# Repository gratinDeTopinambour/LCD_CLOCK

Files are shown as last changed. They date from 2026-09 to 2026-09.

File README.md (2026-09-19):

# ⏱️ LCD_CLOCK

A complete **open-source low-power LCD clock project** based on the **STM32U083RCT6** microcontroller.

This repository contains all the resources required to build the project:

- 📐 **3D Design**: Enclosure and mechanical parts for 3D printing.
- 🔌 **Electronics**: Schematics, PCB layout, BOM, Gerbers, and PDF documentation.
- 💻 **Firmware**: Embedded C software developed using STM32CubeIDE / STM32CubeMX.
- 🖥️ **LCD Display**: Direct driving of a 4-digit LCD display by the STM32.
- ⏰ **Timekeeping**: Utilizes the internal RTC and low-frequency LSE oscillator.
- 🔋 **Power Management**: Leverages low-power peripherals and STOP2 sleep mode.
- 🌡️ **Analog Measurements**: Temperature and battery voltage monitoring via ADC.
- 📖 **Documentation**: Technical files and documents needed for manufacturing and development.

---

## 🖼️ Project Overview

| LCD Clock |
| :---: |
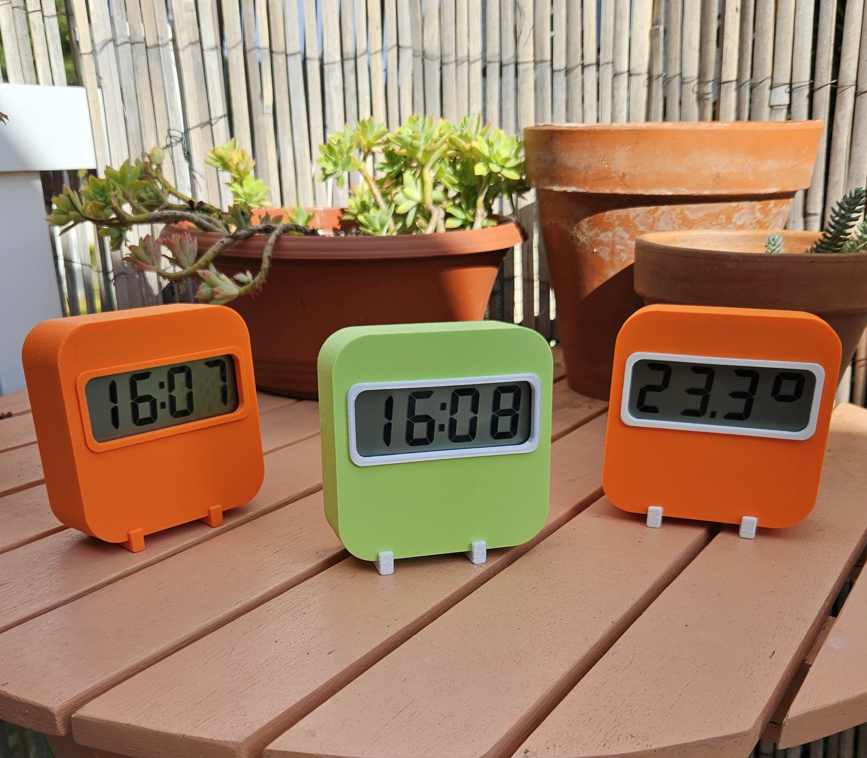
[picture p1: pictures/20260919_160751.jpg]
|  |
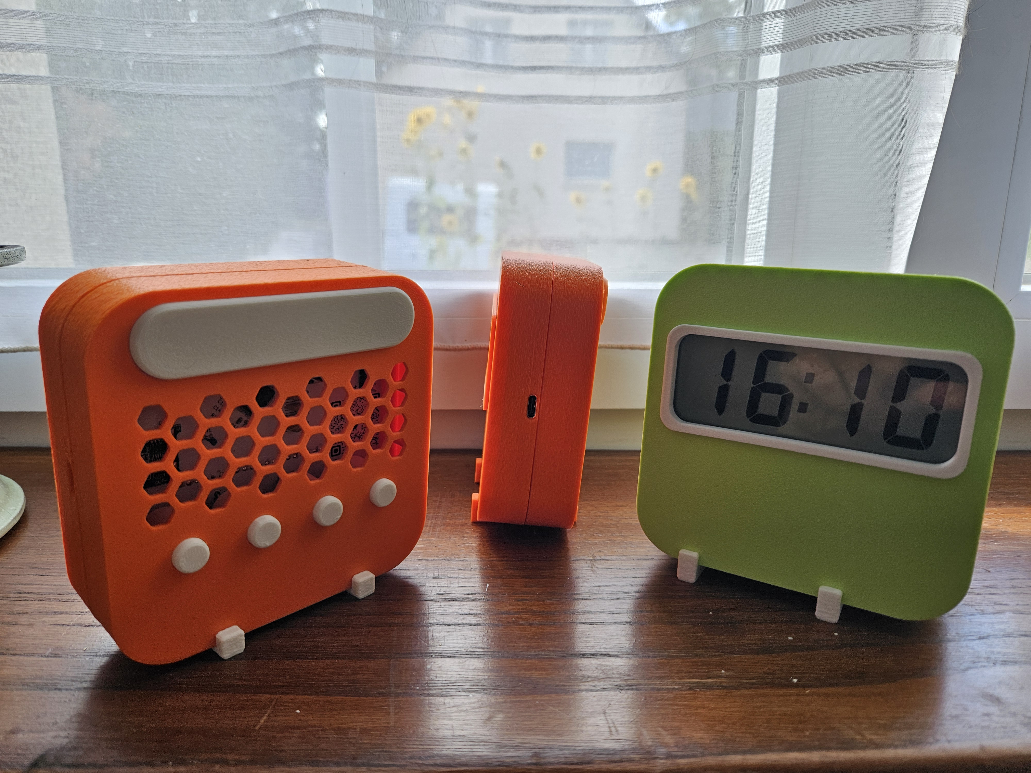
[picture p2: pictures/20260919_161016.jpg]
|  |

---

## 📂 Project Structure

```text
LCD_CLOCK/
│
├── 3D_design/                             # Mechanical design
│   ├── LCD_Clock_back.stl                 # Back part of the enclosure
│   ├── LCD_Clock_button_lumiere.stl       # Light control button
│   ├── LCD_Clock_button.stl               # Control button
│   ├── LCD_Clock_capot.stl                # Enclosure top cover
│   ├── LCD_Clock_dessous.stl              # Bottom part of the enclosure
│   ├── LCD_Clock_face_avant.stl           # Front panel
│   ├── LCD_Clock.3mf                      # Complete 3D project / model
│   └── LCD_Clock.step                     # STEP CAD model
│
├── Electronics/                           # Electronics design
│   ├── BOM/                               # Bill of Materials
│   ├── GERBER/                            # PCB manufacturing files
│   ├── KICAD/                             # KiCad project
│   └── PDF_version/                       # PDF electronics documentation
│
├── pictures/                              # Project photos
│   ├── 20260919_160751.jpg
│   └── 20260919_161016.jpg
│
├── Program/                               # STM32 firmware
│   ├── .settings/                         # STM32CubeIDE settings
│   ├── Core/                              # Application code and configuration
│   ├── Drivers/                           # Drivers and libraries
│   ├── .cproject                          # Eclipse project configuration
│   ├── .mxproject                         # STM32CubeMX configuration
│   ├── .project                           # STM32CubeIDE project file
│   ├── LCD_CLOCK Debug.launch             # Debug launch configuration
│   ├── LCD_CLOCK.ioc                      # STM32CubeMX configuration file
│   └── STM32U083RCTX_FLASH.ld             # Linker script
│
├── README.md                              # Main documentation
└── LICENSE                                # Project license

---

## ⚡ Technical Specifications

* **Microcontroller**: STM32U083RCT6 (Ultra-low-power ARM Cortex-M0+).
* **Display**: 4-digit LCD directly driven by the microcontroller.
* **Timekeeping**: RTC with LSE low-frequency oscillator.
* **Low Power**: Leverages RTC/LPTIM peripherals and STOP2 mode.
* **Measurements**: Temperature and battery voltage measured via ADC.
* **PCB Design**: Designed with **KiCad**, Gerber files and BOM included.
* **Power Supply**: Designed for battery operation.

---

## 🖨️ 3D Printed Enclosure

Parts are located in the `3D_design/` directory.

| Part | Format | Description |
| :--- | :--- | :--- |
| `LCD_Clock.3mf` | `.3mf` | 3D enclosure model |
| `LCD_Clock.step` | `.step` | CAD enclosure model |
| `LCD_Clock_capot.stl` | `.stl` | Top cover |
| `LCD_Clock_face_avant.stl` | `.stl` | Front panel |
| `LCD_Clock_back.stl` | `.stl` | Back part |
| `LCD_Clock_dessous.stl` | `.stl` | Bottom part |
| `LCD_Clock_button.stl` | `.stl` | Control button |
| `LCD_Clock_button_lumiere.stl` | `.stl` | Light control button |

---

## 💻 Firmware & Development

Source code is located in `Program/`.

### Prerequisites

* [STM32CubeIDE](https://www.st.com/en/development-tools/stm32cubeide.html) (recent version)
* Debugger / Programmer (ST-Link V2 / V3)

### Building and Flashing

1. Open **STM32CubeIDE**.
2. Import the project from `Program/`.
3. If you wish to modify peripheral configurations, open the `LCD_CLOCK.ioc` file.
4. Build (`Build Project`) then flash the microcontroller using the included debug configuration (`LCD_CLOCK Debug.launch`).

---

## 🏭 PCB Manufacturing

To manufacture the PCB:

1. Production-ready manufacturing files are located in `Electronics/GERBER/`.
2. The Bill of Materials (BOM) is available in `Electronics/BOM/`.
3. Original design files are available in `Electronics/KICAD/`.
4. Schematics and documentation are available in `Electronics/PDF_version/`.

---

## 📖 Documentation

Technical documentation for this project can be found in the `Electronics/PDF_version/` and `Program/` directories.

---

## 📜 License

This project is released under an open-source license. You are free to use, modify, and distribute it.

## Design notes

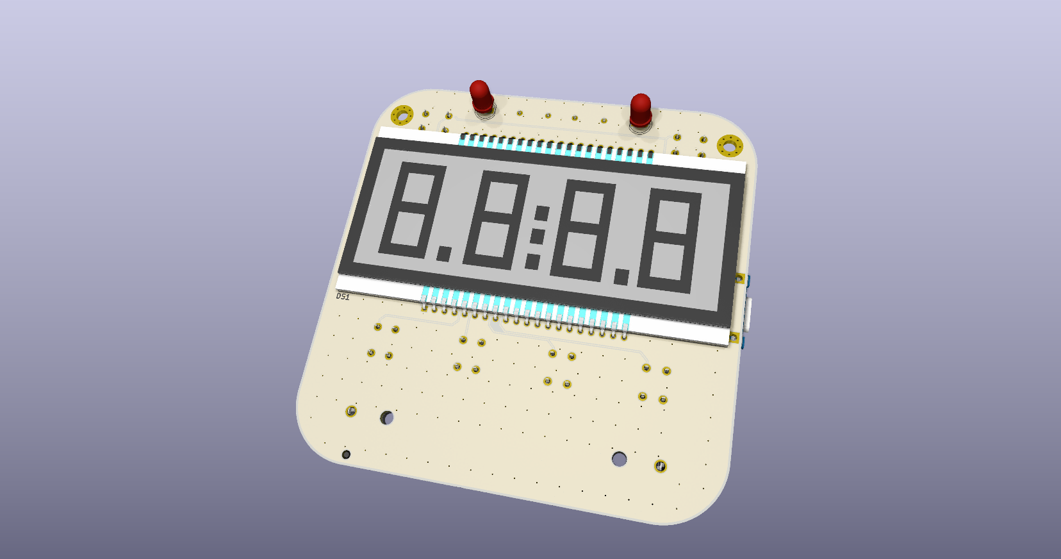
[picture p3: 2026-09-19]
Electronics/PDF_version/LCD_CLOCK_bottom.png

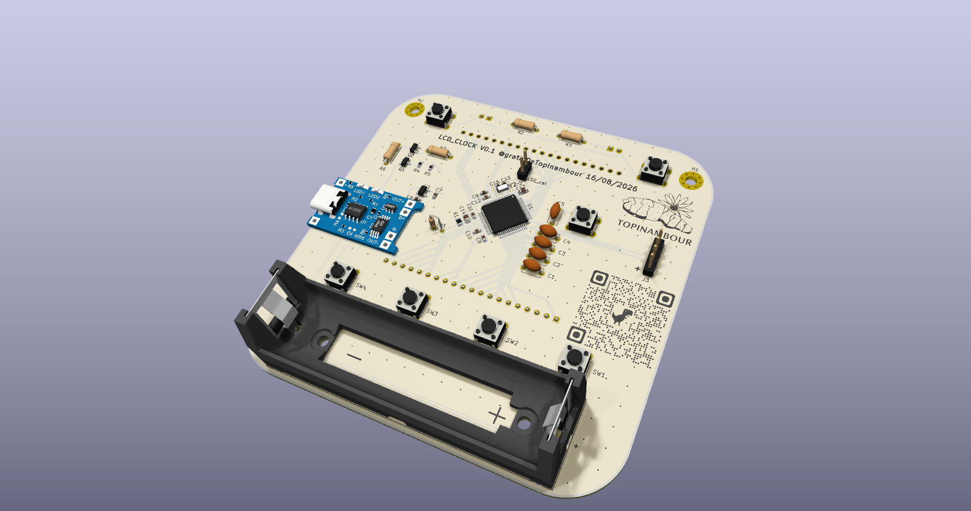
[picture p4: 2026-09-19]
Electronics/PDF_version/LCD_CLOCK.png

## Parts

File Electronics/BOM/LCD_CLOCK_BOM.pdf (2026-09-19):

Feuille1
Reference Value | Footprint
B1 | BHC-18650-1P
C1 | 100nF | C_Disc_D5.0mm_W2.5mm_P5.00mm
C2 | 100nF | C_Disc_D5.0mm_W2.5mm_P5.00mm
C3 | 100nF | C_Disc_D5.0mm_W2.5mm_P5.00mm
C4 | 100nF | C_Disc_D5.0mm_W2.5mm_P5.00mm
C5 | 100nF | C_Disc_D5.0mm_W2.5mm_P5.00mm
C6 | 1uF | 0603_1608Metric
C7 | 1uF | 0603_1608Metric
C8 | 100nF | 0603_1608Metric
C9 | 1uF | 0603_1608Metric
C10 | 1uF | 0603_1608Metric
C11 | 100nF | 0603_1608Metric
C12 | 100nF | 0603_1608Metric
C13 | 100nF | 0805_2012Metric
C14 | 100nF | 0805_2012Metric
C15 | 12pF | 0402_1005Metric
C16 | 12pF | 0402_1005Metric
D1 | LED | LED_D5.0mm
D2 | LED | LED_D5.0mm
DS1 | DE_158-RS-20_6.35 | DE158RS20635
Q1 | AO3401A | SOT-23
Q2 | AO3400A | SOT-23
R1 | 10k | 0805_2012Metric
R2 | 270
R3 | 270
R4 | 22k
R5 | 22k
R6 | 100k
R7 | 22k
SW1 | H1 | Button_Switch_THT:SW_PUSH_6mm_H5mm
SW2 | H2
SW3 | M1
SW4 | M2
SW5 | RST | Button_Switch_THT:SW_PUSH_6mm_H5mm
SW6 | Light | Button_Switch_THT:SW_PUSH_6mm_H5mm
SW7 | Light | Button_Switch_THT:SW_PUSH_6mm_H5mm
TH1 | TT7-10KC8-3
U1 | STM32U073R8Tx | LQFP-64_10x10mm_P0.5mm
U2 | TLV70233_SOT23-5 | SOT-23-5
Y2 | ABS07-32,768KHZ-1-T | ABS07

part | datasheet

DE158

TT7-10KC8-3++(rev+01)

stm32u073x8

# TME ref

BHC-18650-1P

CBR04C120F5GAC
CBR04C120F5GAC

DE158-RS-20/8.4
AO3401A
AO3400A

TT7-10KC3-11

STM32U073R8T6

ABS07-32.768KHZ-1

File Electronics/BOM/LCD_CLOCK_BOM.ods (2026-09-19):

Reference | Value | Footprint | part | datasheet | TME ref
B1 | BHC-18650-1P |  |  |  | BHC-18650-1P
C1 | 100nF | C_Disc_D5.0mm_W2.5mm_P5.00mm
C2 | 100nF | C_Disc_D5.0mm_W2.5mm_P5.00mm
C3 | 100nF | C_Disc_D5.0mm_W2.5mm_P5.00mm
C4 | 100nF | C_Disc_D5.0mm_W2.5mm_P5.00mm
C5 | 100nF | C_Disc_D5.0mm_W2.5mm_P5.00mm
C6 | 1uF | 0603_1608Metric
C7 | 1uF | 0603_1608Metric
C8 | 100nF | 0603_1608Metric
C9 | 1uF | 0603_1608Metric
C10 | 1uF | 0603_1608Metric
C11 | 100nF | 0603_1608Metric
C12 | 100nF | 0603_1608Metric
C13 | 100nF | 0805_2012Metric
C14 | 100nF | 0805_2012Metric
C15 | 12pF | 0402_1005Metric |  |  | CBR04C120F5GAC
C16 | 12pF | 0402_1005Metric |  |  | CBR04C120F5GAC
D1 | LED | LED_D5.0mm
D2 | LED | LED_D5.0mm
DS1 | DE_158-RS-20_6.35 | DE158RS20635 |  | DE158 | DE158-RS-20/8.4
Q1 | AO3401A | SOT-23 |  |  | AO3401A
Q2 | AO3400A | SOT-23 |  |  | AO3400A
R1 | 10k | 0805_2012Metric
R2 | 270
R3 | 270
R4 | 22k
R5 | 22k
R6 | 100k
R7 | 22k
SW1 | H1 | Button_Switch_THT:SW_PUSH_6mm_H5mm
SW2 | H2
SW3 | M1
SW4 | M2
SW5 | RST | Button_Switch_THT:SW_PUSH_6mm_H5mm
SW6 | Light | Button_Switch_THT:SW_PUSH_6mm_H5mm
SW7 | Light | Button_Switch_THT:SW_PUSH_6mm_H5mm
TH1 | TT7-10KC8-3 |  |  | TT7-10KC8-3++(rev+01) | TT7-10KC3-11
U1 | STM32U073R8Tx | LQFP-64_10x10mm_P0.5mm |  | stm32u073x8 | STM32U073R8T6
U2 | TLV70233_SOT23-5 | SOT-23-5
Y2 | ABS07-32,768KHZ-1-T | ABS07 |  |  | ABS07-32.768KHZ-1

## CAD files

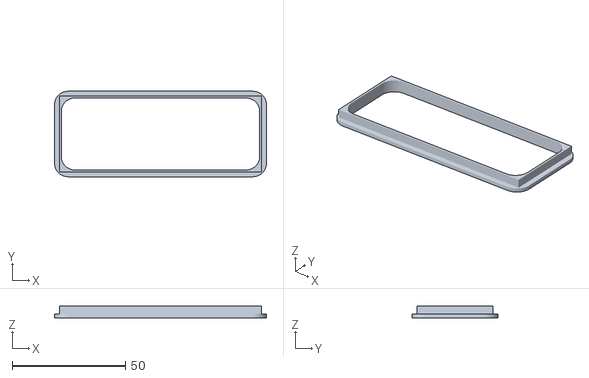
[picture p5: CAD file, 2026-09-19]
3D_design/LCD_Clock_face_avant.stl
93.5 x 37.8 x 5.10

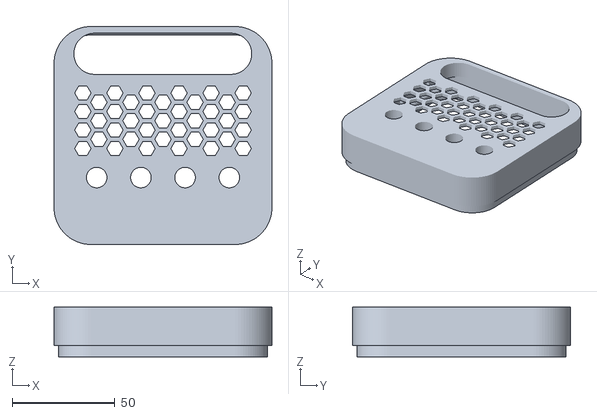
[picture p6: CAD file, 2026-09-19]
3D_design/LCD_Clock_back.stl
106.0 x 106.0 x 24.1

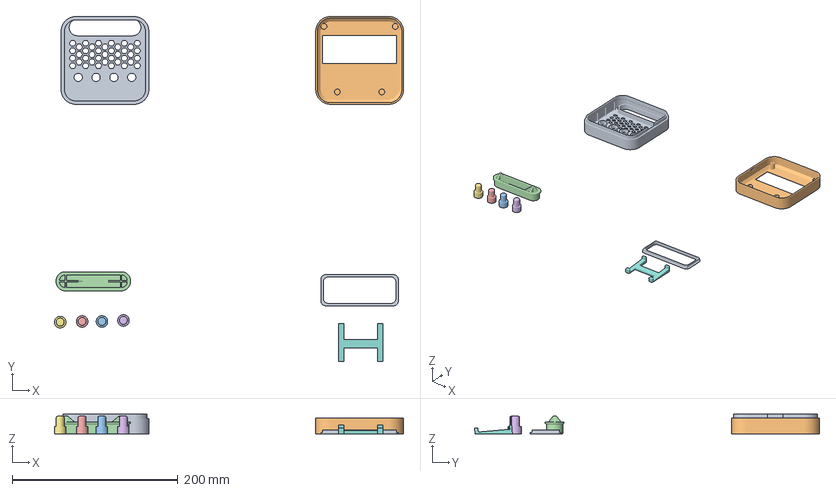
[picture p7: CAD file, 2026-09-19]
3D_design/LCD_Clock.3mf
421.2 x 416.2 x 24.1 mm
LCD_Clock_back.stl
LCD_Clock_capot.stl
LCD_Clock_boutton.stl x 4
LCD_Clock_boutton_lumiere.stl
LCD_Clock_dessous.stl
LCD_Clock_face_avant.stl

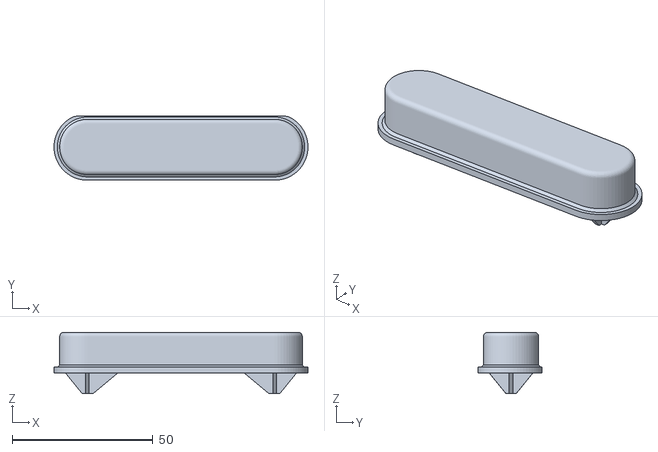
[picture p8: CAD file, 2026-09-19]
3D_design/LCD_Clock_boutton_lumiere.stl
90.1 x 22.9 x 21.8

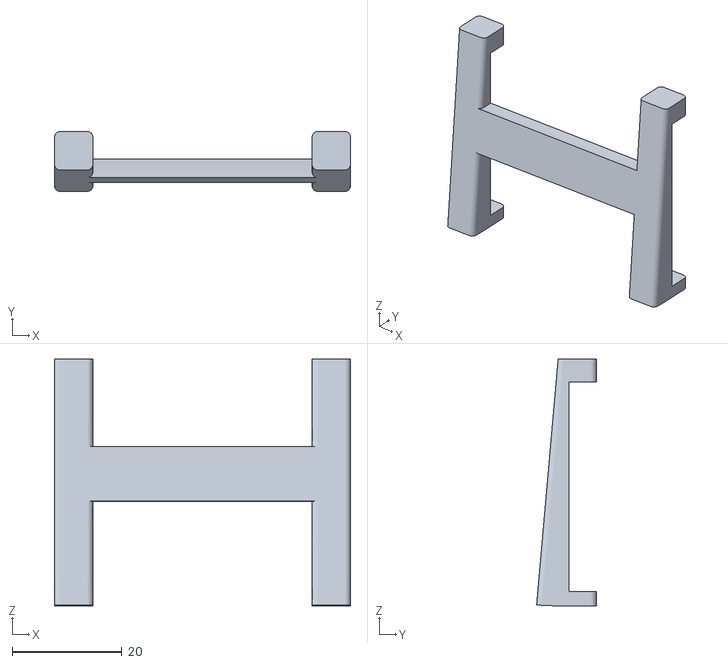
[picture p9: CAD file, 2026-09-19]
3D_design/LCD_Clock_dessous.stl
54.0 x 10.9 x 45.0

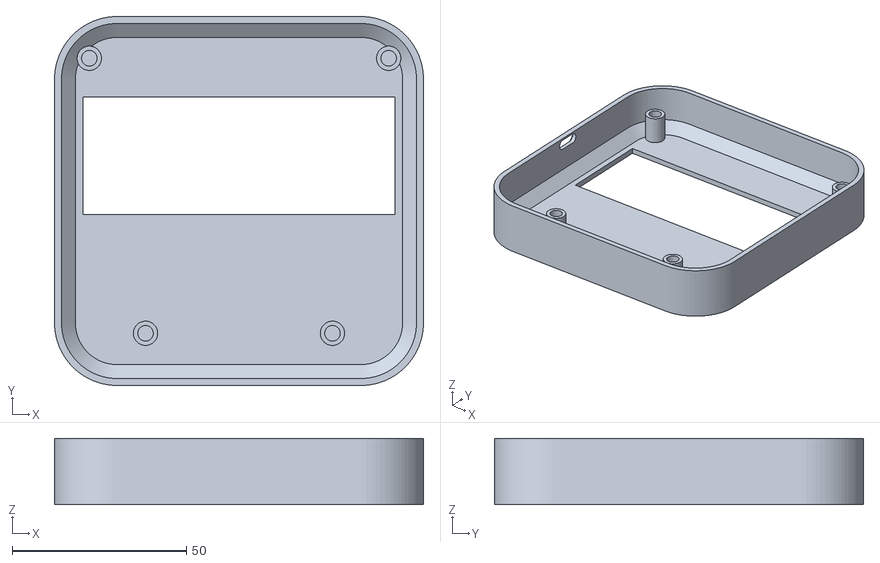
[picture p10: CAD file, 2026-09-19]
3D_design/LCD_Clock_capot.stl
106.0 x 106.0 x 19.0

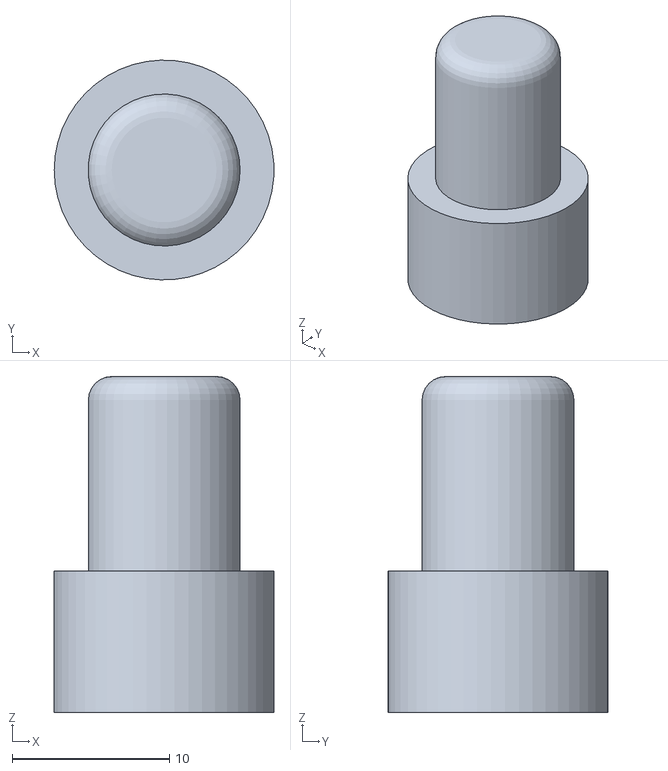
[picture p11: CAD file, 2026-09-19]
3D_design/LCD_Clock_boutton.stl
14.0 x 14.0 x 21.4

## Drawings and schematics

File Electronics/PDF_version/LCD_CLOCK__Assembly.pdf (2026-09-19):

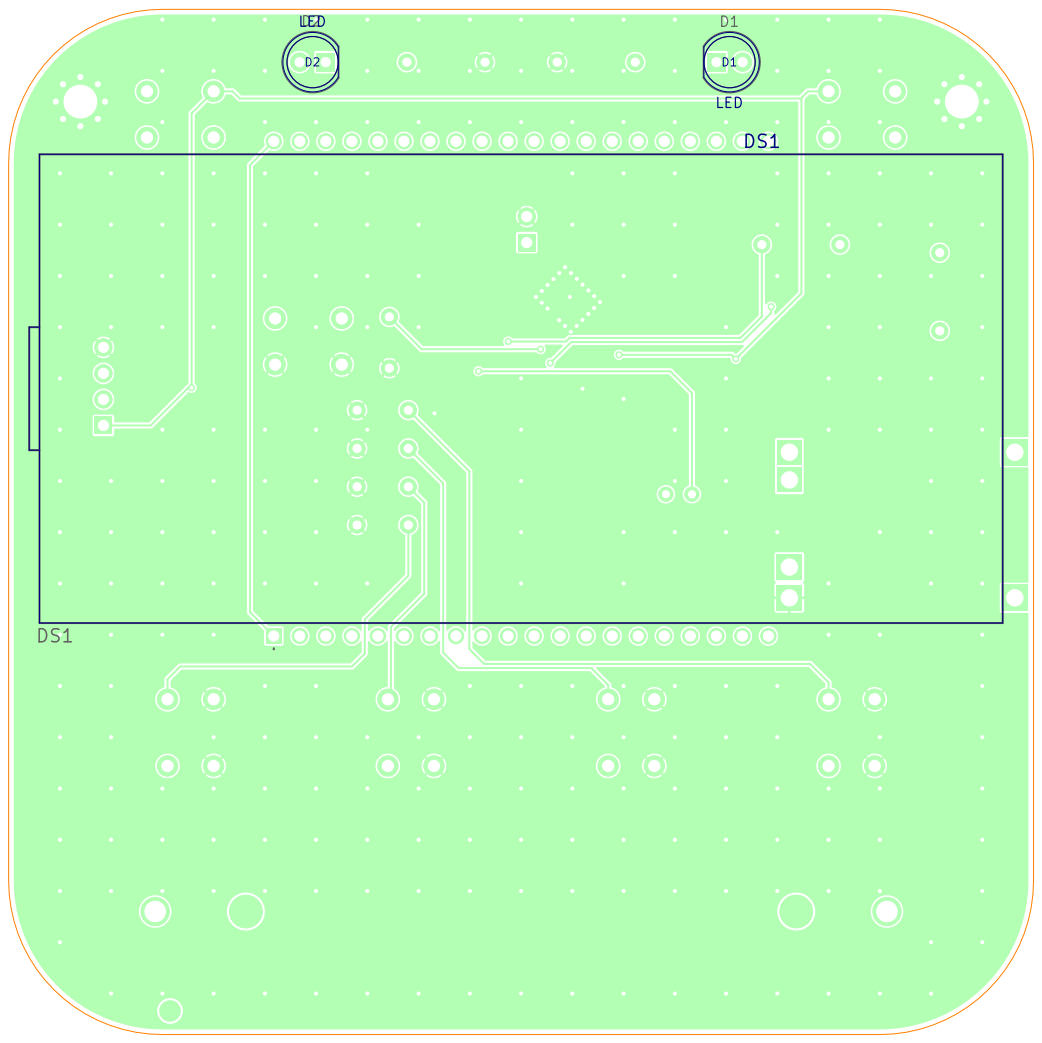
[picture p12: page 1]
D Date:; Size: A4; Rev:; LED; D1 LED

Board2Pdf: Colored BOT - Page 1/2

Sheet: Colored BOT
File: LCD_CLOCK.kicad_pcb
Title:
KiCad E.D.A. 10.0.3

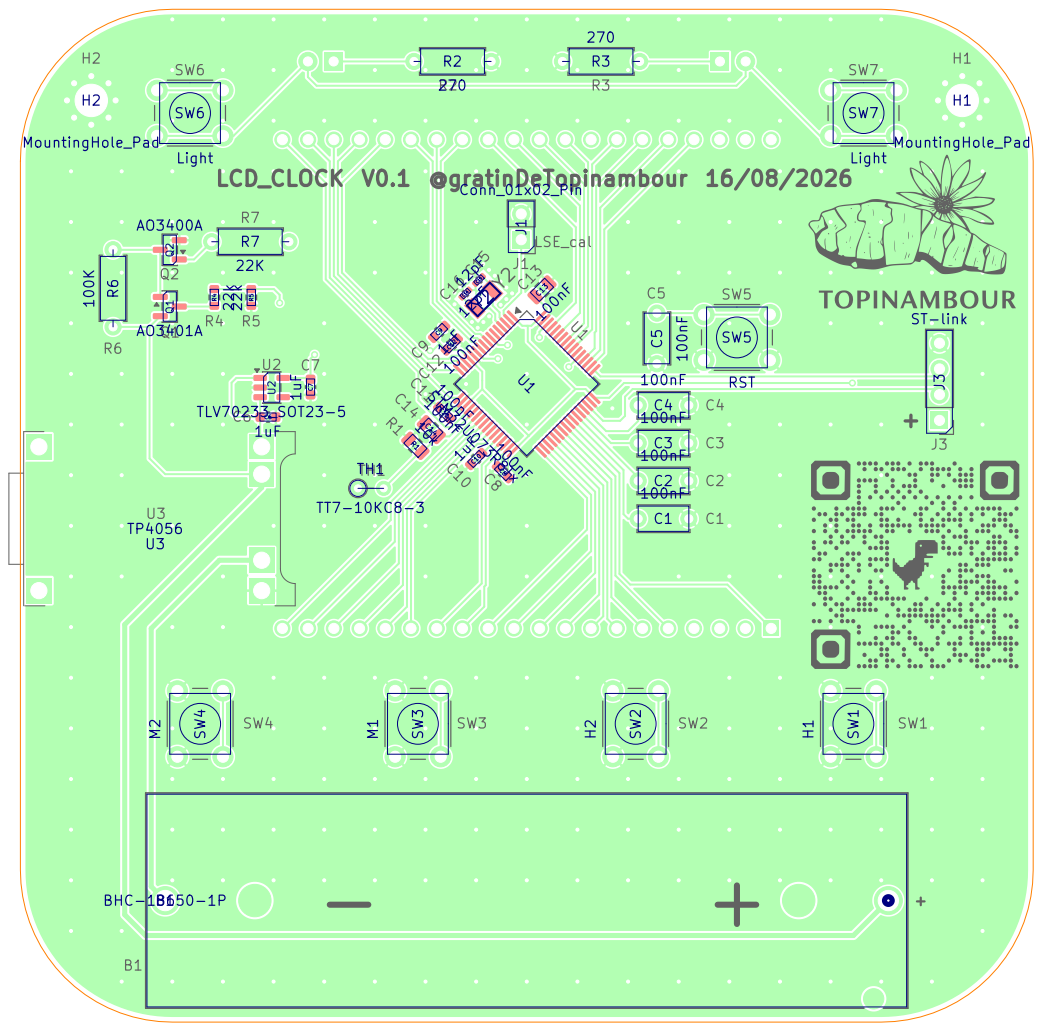
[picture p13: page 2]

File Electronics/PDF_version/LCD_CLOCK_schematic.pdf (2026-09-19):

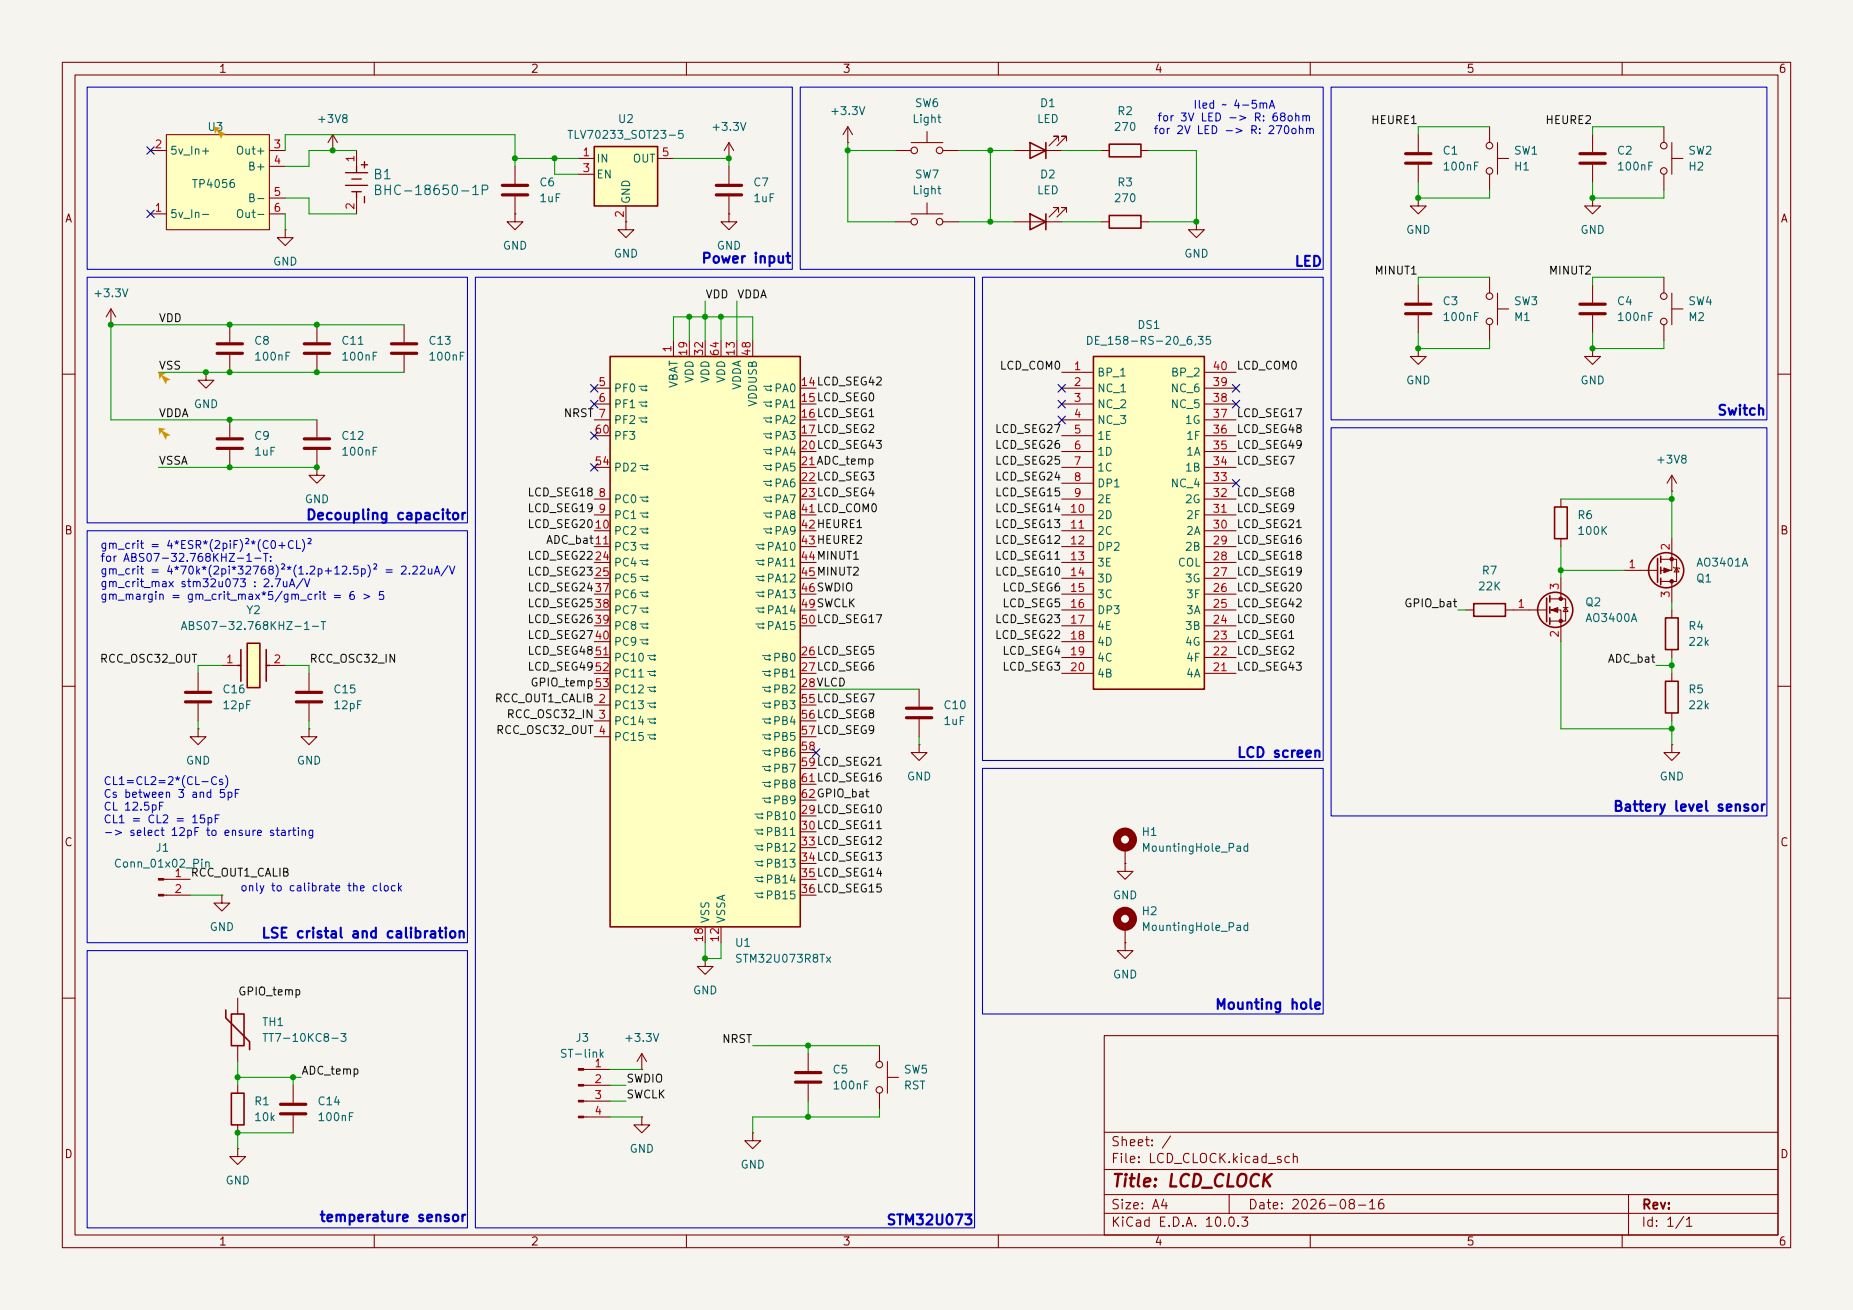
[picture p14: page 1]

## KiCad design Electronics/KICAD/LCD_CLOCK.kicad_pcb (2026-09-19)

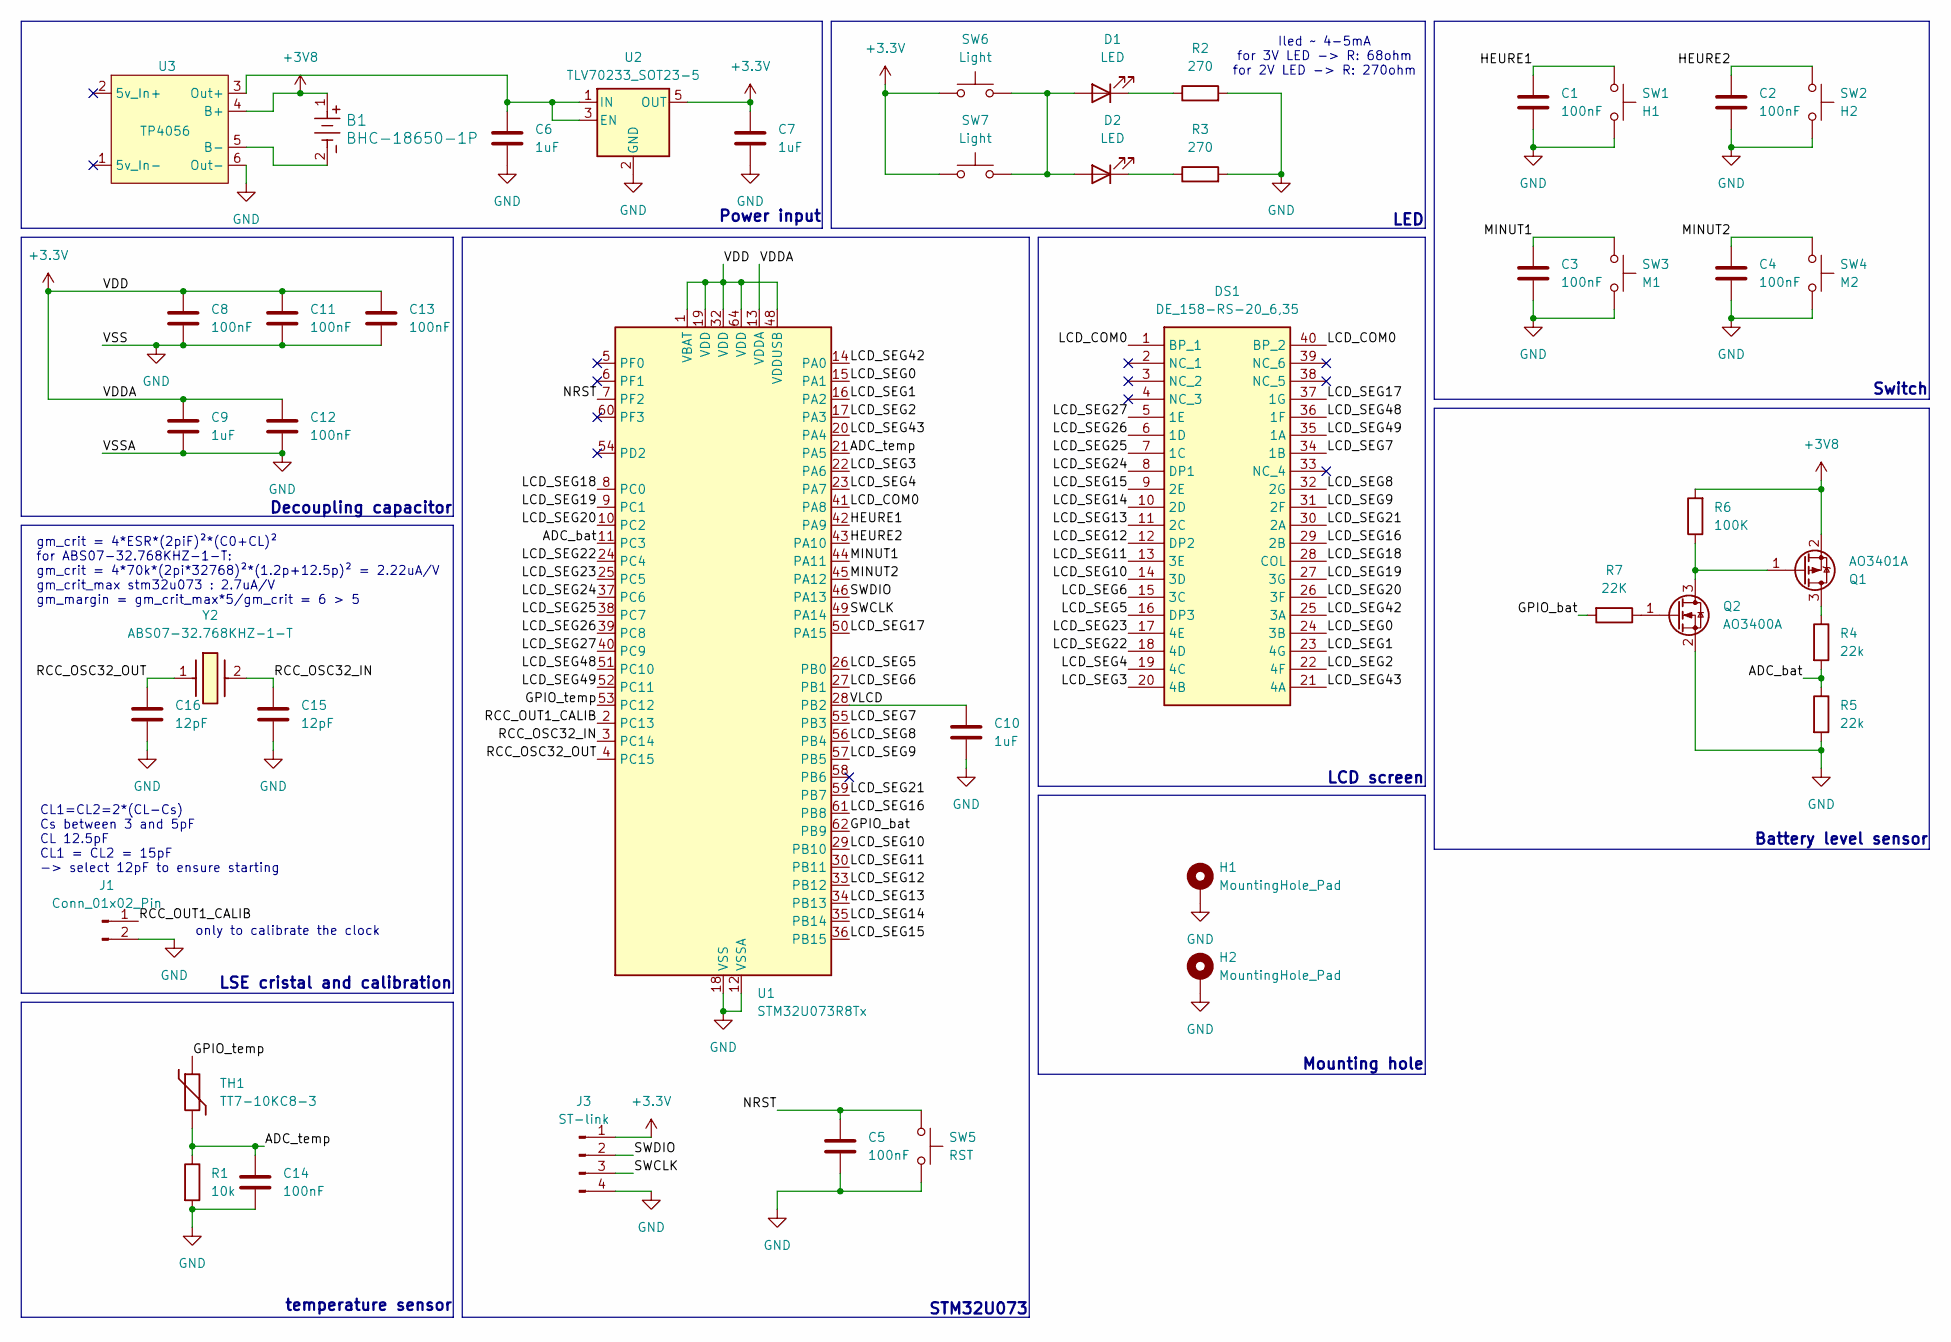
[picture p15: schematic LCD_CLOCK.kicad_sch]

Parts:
B1: BHC-18650-1P; BHC-18650-1P_COM
C1, C2, C3, C4, C5: 100nF; C_Disc_D5.0mm_W2.5mm_P5.00mm
C6, C7, C9, C10: 1uF; C_0603_1608Metric
C8, C11, C12: 100nF; C_0603_1608Metric
C13, C14: 100nF; C_0805_2012Metric
C15, C16: 12pF; C_0402_1005Metric
D1, D2: LED; LED_D5.0mm
DS1: DE_158-RS-20_6,35; DE158RS20635; Manufacturer_Part_Number DE 158-RS-20/6,35
H1, H2: MountingHole_Pad; MountingHole_3.2mm_M3_Pad_Via
J1: Conn_01x02_Pin; PinHeader_1x02_P2.54mm_Vertical
J3: ST-link; PinHeader_1x04_P2.54mm_Vertical
Q1: AO3401A; SOT-23
Q2: AO3400A; SOT-23
R1: 10k; R_0805_2012Metric
R2, R3: 270; R_Axial_DIN0207_L6.3mm_D2.5mm_P7.62mm_Horizontal
R4, R5: 22k; R_0603_1608Metric
R6: 100K; R_Axial_DIN0207_L6.3mm_D2.5mm_P7.62mm_Horizontal
R7: 22K; R_Axial_DIN0207_L6.3mm_D2.5mm_P7.62mm_Horizontal
SW1: H1; SW_PUSH_6mm_H5mm
SW2: H2; SW_PUSH_6mm_H5mm
SW3: M1; SW_PUSH_6mm_H5mm
SW4: M2; SW_PUSH_6mm_H5mm
SW5: RST; SW_PUSH_6mm_H5mm
SW6, SW7: Light; SW_PUSH_6mm_H5mm
TH1: TT7-10KC8-3; R_Axial_DIN0204_L3.6mm_D1.6mm_P2.54mm_Vertical
U1: STM32U073R8Tx; LQFP-64_10x10mm_P0.5mm
U2: TLV70233_SOT23-5; SOT-23-5
U3: TP4056; Module_TP4056
Y2: ABS07-32.768KHZ-1-T; ABS07; Manufacturer_Part_Number ABS07-32.768KHZ-1-T

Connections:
+3.3V: C7.1, C8.1, C9.1, C11.1, C12.1, C13.1, J3.1, SW6.1, SW7.1, U1.1 (VBAT), U1.13 (VDDA), U1.19 (VDD), U1.32 (VDD), U1.48 (VDDUSB), U1.64 (VDD), U2.5 (OUT)
+3V8: B1.1, Q1.2 (S), R6.2, U3.4 (B+)
/ADC_bat: R4.2, R5.1, U1.11 (PC3)
/ADC_temp: C14.1, R1.1, TH1.2, U1.21 (PA5)
/GPIO_bat: R7.2, U1.62 (PB9)
/GPIO_temp: TH1.1, U1.53 (PC12)
/HEURE1: C1.2, SW1.1, U1.42 (PA9)
/HEURE2: C2.2, SW2.1, U1.43 (PA10)
/LCD_COM0: DS1.1 (BP_1), DS1.40 (BP_2), U1.41 (PA8)
/LCD_SEG0: DS1.24 (3B), U1.15 (PA1)
/LCD_SEG1: DS1.23 (4G), U1.16 (PA2)
/LCD_SEG2: DS1.22 (4F), U1.17 (PA3)
/LCD_SEG3: DS1.20 (4B), U1.22 (PA6)
/LCD_SEG4: DS1.19 (4C), U1.23 (PA7)
/LCD_SEG5: DS1.16 (DP3), U1.26 (PB0)
/LCD_SEG6: DS1.15 (3C), U1.27 (PB1)
/LCD_SEG7: DS1.34 (1B), U1.55 (PB3)
/LCD_SEG8: DS1.32 (2G), U1.56 (PB4)
/LCD_SEG9: DS1.31 (2F), U1.57 (PB5)
/LCD_SEG10: DS1.14 (3D), U1.29 (PB10)
/LCD_SEG11: DS1.13 (3E), U1.30 (PB11)
/LCD_SEG12: DS1.12 (DP2), U1.33 (PB12)
/LCD_SEG13: DS1.11 (2C), U1.34 (PB13)
/LCD_SEG14: DS1.10 (2D), U1.35 (PB14)
/LCD_SEG15: DS1.9 (2E), U1.36 (PB15)
/LCD_SEG16: DS1.29 (2B), U1.61 (PB8)
/LCD_SEG17: DS1.37 (1G), U1.50 (PA15)
/LCD_SEG18: DS1.28 (COL), U1.8 (PC0)
/LCD_SEG19: DS1.27 (3G), U1.9 (PC1)
/LCD_SEG20: DS1.26 (3F), U1.10 (PC2)
/LCD_SEG21: DS1.30 (2A), U1.59 (PB7)
/LCD_SEG22: DS1.18 (4D), U1.24 (PC4)
/LCD_SEG23: DS1.17 (4E), U1.25 (PC5)
/LCD_SEG24: DS1.8 (DP1), U1.37 (PC6)
/LCD_SEG25: DS1.7 (1C), U1.38 (PC7)
/LCD_SEG26: DS1.6 (1D), U1.39 (PC8)
/LCD_SEG27: DS1.5 (1E), U1.40 (PC9)
/LCD_SEG42: DS1.25 (3A), U1.14 (PA0)
/LCD_SEG43: DS1.21 (4A), U1.20 (PA4)
/LCD_SEG48: DS1.36 (1F), U1.51 (PC10)
/LCD_SEG49: DS1.35 (1A), U1.52 (PC11)
/MINUT1: C3.2, SW3.1, U1.44 (PA11)
/MINUT2: C4.2, SW4.1, U1.45 (PA12)
/NRST: C5.2, SW5.1, U1.7 (PF2)
/RCC_OSC32_IN: C15.1, U1.3 (PC14), Y2.2
/RCC_OSC32_OUT: C16.1, U1.4 (PC15), Y2.1
/RCC_OUT1_CALIB: J1.1, U1.2 (PC13)
/SWCLK: J3.3, U1.49 (PA14)
/SWDIO: J3.2, U1.46 (PA13)
/VLCD: C10.1, U1.28 (PB2)
GND: C1.1, C2.1, C3.1, C4.1, C5.1, C6.2, C7.2, C8.2, C9.2, C10.2, C11.2, C12.2, C13.2, C14.2, C15.2, C16.2, H1.1 (1_1), H2.1 (1_1), J1.2, J3.4, Q2.2 (S), R1.2, R2.2, R3.2, R5.2, SW1.2, SW2.2, SW3.2, SW4.2, SW5.2, U1.12 (VSSA), U1.18 (VSS), U1.31 (VSS), U1.47 (VSS), U1.63 (VSS), U2.2 (GND), U3.6 (Out-)
unnamed: D1.2 (A), D2.2 (A), SW6.2, SW7.2
unnamed: D1.1 (K), R2.1
unnamed: D2.1 (K), R3.1
unnamed: Q1.3 (D), R4.1
unnamed: Q1.1 (G), Q2.3 (D), R6.1
unnamed: Q2.1 (G), R7.1
unnamed: C6.1, U2.1 (IN), U2.3 (EN), U3.3 (Out+)
unnamed: B1.2, U3.5 (B-)

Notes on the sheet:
LCD screen
Power input
Battery level sensor
LED
Switch
Iled ~ 4-5mA for 3V LED -> R: 68ohm for 2V LED -> R: 270ohm
CL1=CL2=2*(CL-Cs) Cs between 3 and 5pF CL 12.5pF CL1 = CL2 = 15pF -> select 12pF to ensure starting
STM32U073
Decoupling capacitor
LSE cristal and calibration
Mounting hole
temperature sensor
gm_crit = 4*ESR*(2piF)²*(C0+CL)² for ABS07-32.768KHZ-1-T: gm_crit = 4*70k*(2pi*32768)²*(1.2p+12.5p)² = 2.22uA/V gm_crit_max stm32u073 : 2.7uA/V gm_margin = gm_crit_max*5/gm_crit = 6 > 5
only to calibrate the clock

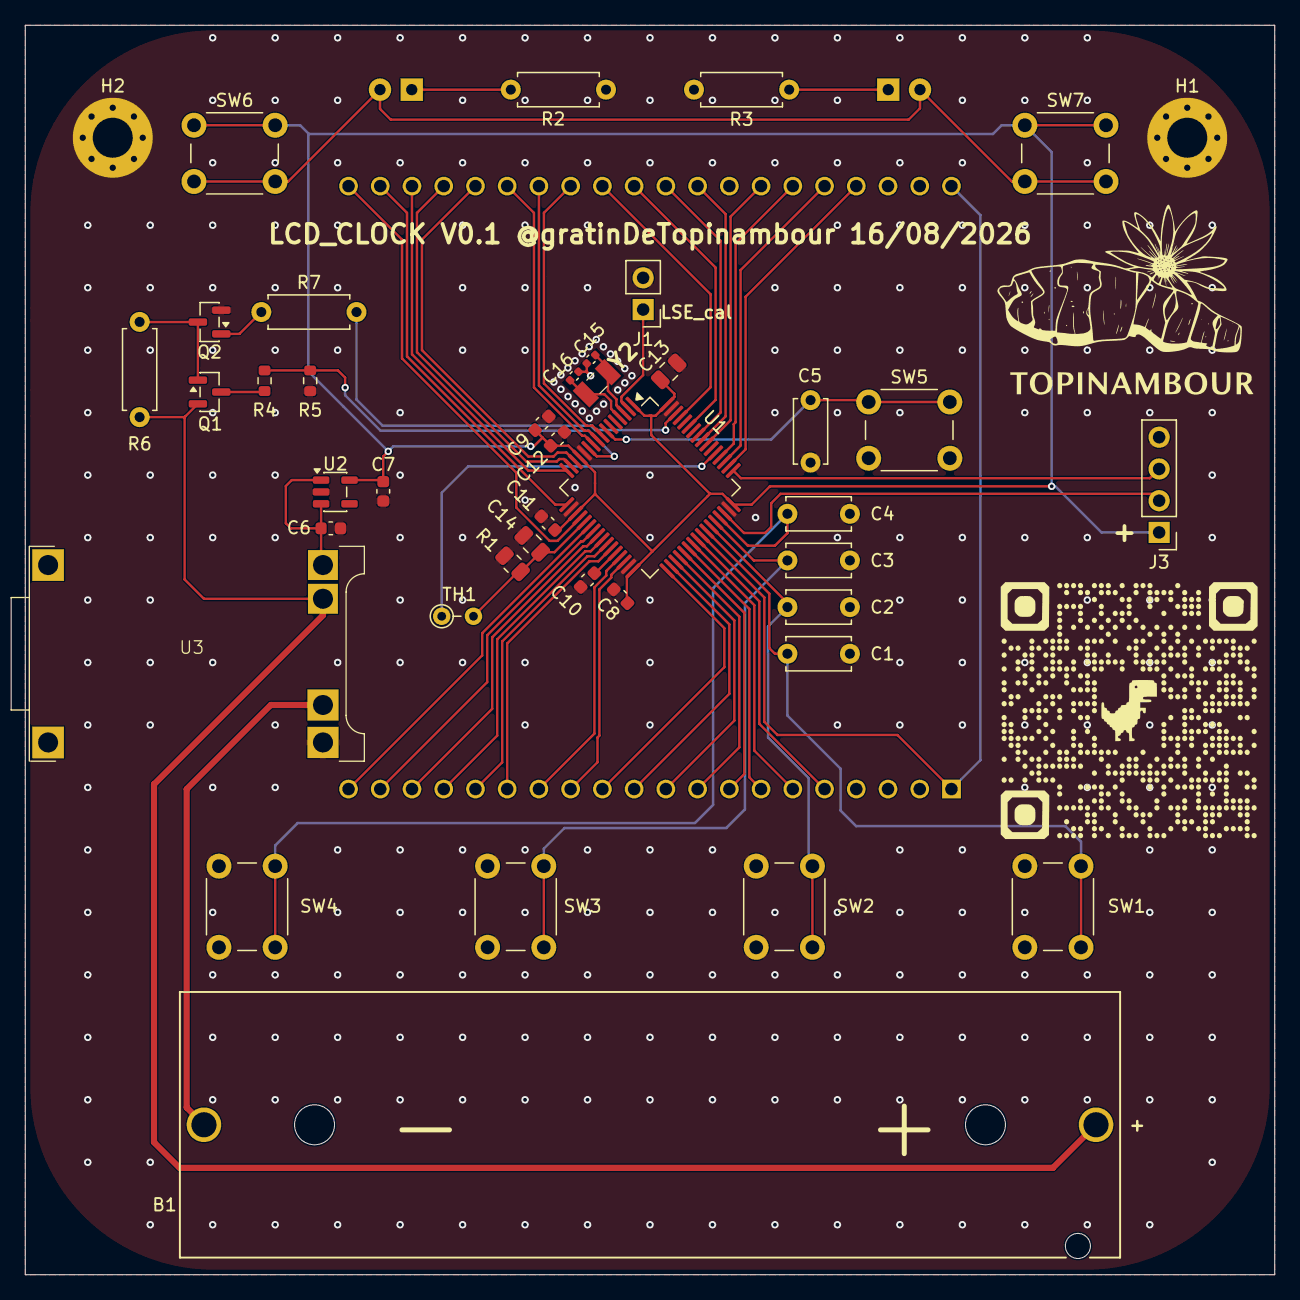
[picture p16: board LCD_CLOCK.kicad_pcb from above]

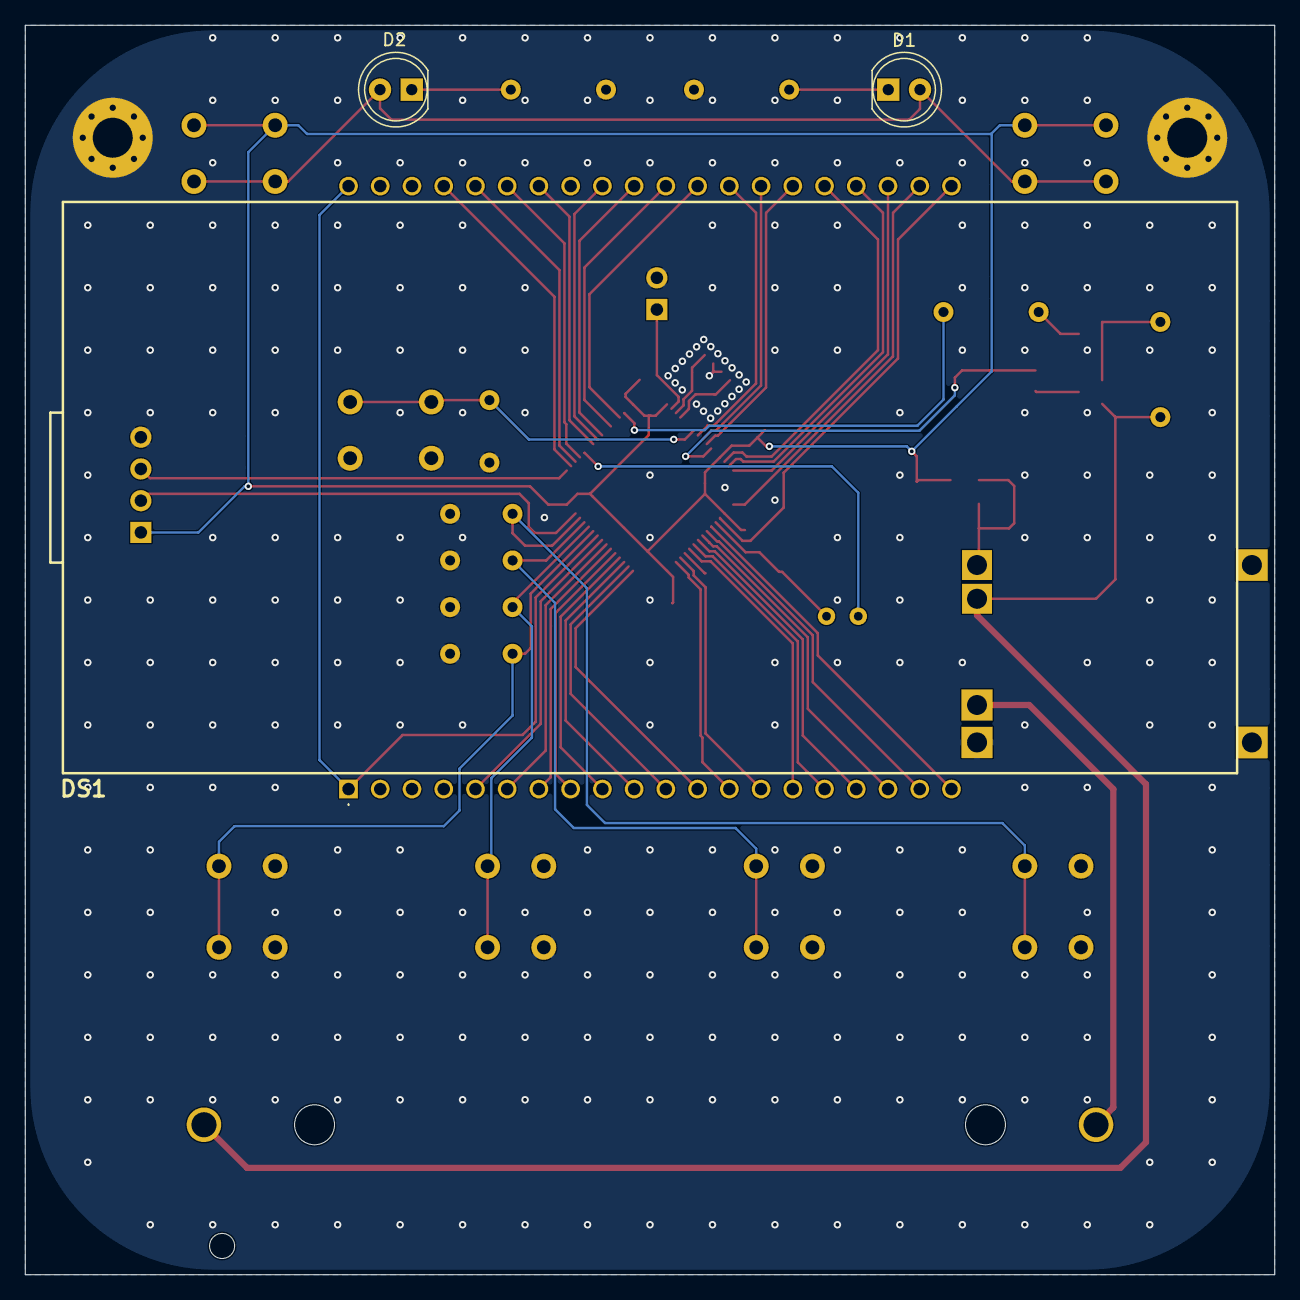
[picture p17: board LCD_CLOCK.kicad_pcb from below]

Board: 2 copper layers, 100.0 x 100.0 mm, 45 parts (3 on the bottom side), 59 nets.

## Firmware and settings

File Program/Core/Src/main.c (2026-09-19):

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
/* Includes ------------------------------------------------------------------*/
#include "main.h"

/* USER CODE BEGIN Includes */
#include "math.h"
#include "LCD_4DIGIT.h"
#include <stdio.h>
/* USER CODE END Includes */

/* USER CODE BEGIN PD */

//variable for TT7-10KC3-11 thermistor
#define R0_NTC 10000.0f
#define T0_NTC 298.15f
#define BETA_NTC 3977.0f
#define R_SERIE 9990.0f
/* USER CODE END PD */

ADC_HandleTypeDef hadc1;
DMA_HandleTypeDef hdma_adc1;

LCD_HandleTypeDef hlcd;

LPTIM_HandleTypeDef hlptim1;
LPTIM_HandleTypeDef hlptim2;

RTC_HandleTypeDef hrtc;

/* USER CODE BEGIN PV */
volatile Flag system_flag = {0};
State system_state = START;
uint16_t temp_value;
uint16_t bat_value;
uint8_t sleep_time = 0;
volatile uint8_t StopMode_Activated = 0;
uint32_t start;

volatile uint16_t adc_dma_buffer[2];

RTC_TimeTypeDef Time = {0};
RTC_DateTypeDef Date = {0};
/* USER CODE END PV */

void SystemClock_Config(void);
static void MX_GPIO_Init(void);
static void MX_DMA_Init(void);
static void MX_ADC1_Init(void);
static void MX_LCD_Init(void);
static void MX_RTC_Init(void);
static void MX_LPTIM1_Init(void);
static void MX_LPTIM2_Init(void);
/* USER CODE BEGIN 0 */
void mini_sprintf(int n, char *s, uint8_t width, char pad)
{

	s[width-1] = '\0';

    for (int8_t i = width - 2; i >= 0; i--) {
        // 2. Fill digits using the absolute value
        if (n > 0 || (i == width - 2 && n == 0)) {
            s[i] = (n % 10) + '0';
            n /= 10;
        }
        // 4. Fill remaining space with padding
        else {
            s[i] = pad;
        }
    }
}

State switch_state(Flag sys_flag)
{
	State state = START;

	if(sys_flag.need_calibration > 400) state = CALIBRATION;
	else if(sys_flag.adc_update)  state = ADC_MEASUREMENT;
	else if(sys_flag.adc_ready)  state = ADC_READ;
	else if(sys_flag.wait_adc) state = WAIT_FOR_ADC;
	else if(sys_flag.bat_update)  state = PRINT_BAT;
	else if(sys_flag.time_update) state = PRINT_TIME;
	else if(sys_flag.temp_update) state = PRINT_TEMP;
	else state = SLEEP_MODE;

	return state;
}

uint8_t Read_ADC(uint16_t *temp_val, uint16_t *bat_val)
{
	float temp_celsius = 0;
	int ADC_temp_value = 0;
	float R_ADC = 0;

	int ADC_bat_value = 0;

	HAL_GPIO_WritePin(BAT_ADC_ENABLE_GPIO_Port, BAT_ADC_ENABLE_Pin, RESET);
	HAL_GPIO_WritePin(TEMP_ADC_ENABLE_GPIO_Port, TEMP_ADC_ENABLE_Pin, RESET);

	ADC_temp_value = adc_dma_buffer[0];
	ADC_bat_value = adc_dma_buffer[1];

	if(ADC_temp_value < 1058) //temp < 0°C
	{
		*temp_val = 0;
	}
	else
	{
		R_ADC = R_SERIE*((4095.0f/(float)ADC_temp_value) - 1.0f);

		float steinhart = logf(R_ADC / R0_NTC) / BETA_NTC;
		steinhart += 1.0f / T0_NTC;
		temp_celsius = (1.0f / steinhart) - 273.15f;
		*temp_val = (uint16_t)(temp_celsius * 10.0f);
	}

	*bat_val = (uint16_t)(660.0*(float)ADC_bat_value/4096.0);


	return 0;
}

uint8_t Print_temp(uint16_t temp_val)
{
	char temp_txt[5] = "   *";

	mini_sprintf(temp_val, temp_txt, sizeof(temp_txt), ' ');

	for (uint8_t i = 0; i < 3; i++) {
		temp_txt[i] = temp_txt[i + 1];
	}

	temp_txt[3] = '*';
	LCD_WriteDigit(temp_txt,0b0010);

	return 0;
}

uint8_t Print_time(uint8_t hour, uint8_t minute)
{
	char time_txt[5] = "0000";
	char minute_txt[3] = "00";

	mini_sprintf(minute, minute_txt, sizeof(minute_txt), '0');
	mini_sprintf(hour, time_txt, sizeof(time_txt), '0');

	for (uint8_t i = 0; i < 2; i++) {
		time_txt[i] = time_txt[i + 2];
	}

	time_txt[2] = minute_txt[0];
	time_txt[3] = minute_txt[1];

	LCD_WriteDigit(time_txt,0b1000);

	return 0;
}

/* USER CODE END 0 */

/**
  * @brief  The application entry point.
  * @retval int
  */
int main(void)
{

  /* MCU Configuration--------------------------------------------------------*/

  /* Reset of all peripherals, Initializes the Flash interface and the Systick. */
  HAL_Init();

  /* Configure the system clock */
  SystemClock_Config();

  /* Initialize all configured peripherals */
  MX_GPIO_Init();
  MX_DMA_Init();
  MX_ADC1_Init();
  MX_LCD_Init();
  MX_RTC_Init();
  MX_LPTIM1_Init();
  MX_LPTIM2_Init();
  /* USER CODE BEGIN 2 */

  HAL_LCD_Clear(&hlcd);

  Time.Hours = 0;
  Time.Minutes = 0;
  Time.Seconds = 0;
  HAL_RTC_SetTime(&hrtc, &Time, RTC_FORMAT_BIN);

  system_flag.adc_update = 1;
  system_flag.need_calibration = 401;
  system_flag.time_update = 1;
//  HAL_RCCEx_PeriphCLKConfig();

  HAL_LPTIM_Counter_Start_IT(&hlptim1);
  HAL_LPTIM_Counter_Start_IT(&hlptim2);

  /* USER CODE END 2 */

  /* Infinite loop */
  /* USER CODE BEGIN WHILE */
  while (1)
  {
	  switch (system_state)
	  {
	  case START:

		  system_state = switch_state(system_flag);
		  break;

	  case CALIBRATION:

		  HAL_ADCEx_Calibration_Start(&hadc1);
		  system_flag.need_calibration = 0;

		  system_state = switch_state(system_flag);
		  break;

	  case ADC_READ:

		  Read_ADC(&temp_value, &bat_value);

		  system_flag.adc_ready = 0;
		  system_flag.wait_adc = 0;

		  if(bat_value < 340)
		  {
			  system_flag.low_battery = 1;
		  }

		  system_state = switch_state(system_flag);
		  break;

	  case ADC_MEASUREMENT:

		  HAL_GPIO_WritePin(TEMP_ADC_ENABLE_GPIO_Port, TEMP_ADC_ENABLE_Pin, SET);
		  HAL_GPIO_WritePin(BAT_ADC_ENABLE_GPIO_Port, BAT_ADC_ENABLE_Pin, SET);

		  start = HAL_GetTick();

		  while ((HAL_GetTick() - start) < 10);

		  HAL_ADC_Start_DMA(&hadc1, (uint32_t*)adc_dma_buffer, 2);

		  system_flag.adc_update = 0;
		  system_flag.wait_adc = 1;

		  system_state = switch_state(system_flag);
		  break;

	  case WAIT_FOR_ADC:

		  system_flag.wait_adc = 1;

		  system_state = switch_state(system_flag);
		  break;

	  case PRINT_TIME:

		  system_flag.time_update = 0;

		  Print_time(Time.Hours, Time.Minutes);

		  sleep_time = 5;

		  system_state = switch_state(system_flag);
		  break;

	  case PRINT_TEMP:

		  system_flag.temp_update = 0;

		  Print_temp(temp_value);

		  sleep_time = 3;

		  system_state = switch_state(system_flag);
		  break;

	  case PRINT_BAT:

		  system_flag.bat_update = 0;

		  LCD_WriteDigit("batt", 0);

		  if(bat_value > 344)
		  {
			  system_flag.low_battery = 0;
		  }

		  sleep_time = 20;

		  system_state = switch_state(system_flag);
		  break;

	  case SLEEP_MODE:

		  if(sleep_time > 1)
		  {
			  HAL_RTCEx_SetWakeUpTimer_IT(&hrtc, sleep_time-1, RTC_WAKEUPCLOCK_CK_SPRE_16BITS, 0);
			  StopMode_Activated = 1;
			  HAL_SuspendTick();
			  HAL_PWREx_EnterSTOP2Mode(PWR_SLEEPENTRY_WFI);

			  HAL_RTCEx_DeactivateWakeUpTimer(&hrtc);
		  }

		  HAL_RTC_GetTime(&hrtc, &Time, RTC_FORMAT_BIN);
		  HAL_RTC_GetDate(&hrtc, &Date, RTC_FORMAT_BIN);

		  if(system_flag.low_battery) system_flag.bat_update = 1;
		  else if(sleep_time == 5) system_flag.temp_update = 1;
		  else if(sleep_time == 3) system_flag.time_update = 1;

		  system_state = switch_state(system_flag);
		  break;

	  default:
		  system_state = START;
		  break;
	  }
    /* USER CODE END WHILE */

    /* USER CODE BEGIN 3 */
  }
  /* USER CODE END 3 */
}

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
/* USER CODE BEGIN 4 */
/**
  * @brief  EXTI line detection callback.
  * @param  GPIO_Pin Specifies the port pin connected to corresponding EXTI line.
  * @retval None
  */
void HAL_GPIO_EXTI_Falling_Callback(uint16_t GPIO_Pin)
{

  if(StopMode_Activated == 1)
  {
	  SystemClock_Config();
	  HAL_ResumeTick();
	  StopMode_Activated = 0;
  }

  HAL_RTC_GetTime(&hrtc, &Time, RTC_FORMAT_BIN);
  HAL_RTC_GetDate(&hrtc, &Date, RTC_FORMAT_BIN);

  if(GPIO_Pin == MINUT2_Pin)
  {
	  Time.Minutes = (Time.Minutes + 1) % 60;
  }
  else if(GPIO_Pin == MINUT1_Pin)
  {
	  Time.Minutes = (Time.Minutes + 10) % 60;
  }
  else if(GPIO_Pin == HEURE2_Pin)
  {
	  Time.Hours = (Time.Hours + 1) % 24;
  }
  else if(GPIO_Pin == HEURE1_Pin)
  {
	  Time.Hours = (Time.Hours + 10) % 24;
  }
  else
  {
	  __NOP();
  }

  HAL_RTC_SetTime(&hrtc, &Time, RTC_FORMAT_BIN);
  system_flag.time_update = 1;
  sleep_time = 3;
}

void HAL_RTCEx_WakeUpTimerEventCallback(RTC_HandleTypeDef *hrtc)
{
	if(StopMode_Activated == 1)
	{
	  SystemClock_Config();
	  HAL_ResumeTick();
	  StopMode_Activated = 0;
	}

}

void HAL_LPTIM_AutoReloadMatchCallback(LPTIM_HandleTypeDef *hlptim)
{
	if(StopMode_Activated == 1)
	{
	  SystemClock_Config();
	  HAL_ResumeTick();
	  StopMode_Activated = 0;
	}

	if (hlptim->Instance == LPTIM2) system_flag.need_calibration++;
	else if (hlptim->Instance == LPTIM1) system_flag.adc_update = 1;
	else __NOP();
}

void HAL_ADC_ConvCpltCallback(ADC_HandleTypeDef *hadc)
{
    if (hadc->Instance == ADC1)
    {
        system_flag.adc_ready = 1;
    }
}
/* USER CODE END 4 */
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


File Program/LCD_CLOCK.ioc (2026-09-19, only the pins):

Mcu.UserName=STM32U083RCTx
PA0.Signal=LCD_SEG42
PA1.Signal=LCD_SEG0
PA10.GPIO_Label=HEURE2
PA10.Signal=GPXTI10
PA15.Signal=LCD_SEG17
PA2.Signal=LCD_SEG1
PA3.Signal=LCD_SEG2
PA4.Signal=LCD_SEG43
PA5.GPIO_Label=TEMP_ADC
PA5.Signal=ADC1_IN9
PA6.Signal=LCD_SEG3
PA7.Signal=LCD_SEG4
PA8.Signal=LCD_COM0
PA9.GPIO_Label=HEURE1
PA9.Signal=GPXTI9
PB0.Signal=LCD_SEG5
PB1.Signal=LCD_SEG6
PB10.Signal=LCD_SEG10
PB11.Signal=LCD_SEG11
PB12.Signal=LCD_SEG12
PB13.Signal=LCD_SEG13
PB14.Signal=LCD_SEG14
PB15.Signal=LCD_SEG15
PB2.Signal=LCD_VLCD
PB3.Signal=LCD_SEG7
PB4.Signal=LCD_SEG8
PB5.Signal=LCD_SEG9
PB7.Signal=LCD_SEG21
PB8.Signal=LCD_SEG16
PB9.GPIO_Label=BAT_ADC_ENABLE
PB9.Signal=GPIO_Output
PC0.Signal=LCD_SEG18
PC1.Signal=LCD_SEG19
PC10.Signal=LCD_SEG48
PC11.Signal=LCD_SEG49
PC12.GPIO_Label=TEMP_ADC_ENABLE
PC12.Signal=GPIO_Output
PC13.Signal=RTC_OUT1
PC14-OSC32_IN.Signal=RCC_OSC32_IN
PC15-OSC32_OUT.Signal=RCC_OSC32_OUT
PC2.Signal=LCD_SEG20
PC3.GPIO_Label=BAT_ADC
PC3.Signal=ADC1_IN3
PC4.Signal=LCD_SEG22
PC5.Signal=LCD_SEG23
PC6.Signal=LCD_SEG24
PC7.Signal=LCD_SEG25
PC8.Signal=LCD_SEG26
PC9.Signal=LCD_SEG27

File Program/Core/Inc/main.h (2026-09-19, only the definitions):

#define BAT_ADC_Pin GPIO_PIN_3
#define BAT_ADC_GPIO_Port GPIOC
#define TEMP_ADC_Pin GPIO_PIN_5
#define TEMP_ADC_GPIO_Port GPIOA
#define HEURE1_Pin GPIO_PIN_9
#define HEURE1_GPIO_Port GPIOA
#define HEURE1_EXTI_IRQn EXTI4_15_IRQn
#define HEURE2_Pin GPIO_PIN_10
#define HEURE2_GPIO_Port GPIOA
#define HEURE2_EXTI_IRQn EXTI4_15_IRQn
#define MINUT1_Pin GPIO_PIN_11
#define MINUT1_GPIO_Port GPIOA
#define MINUT1_EXTI_IRQn EXTI4_15_IRQn
#define MINUT2_Pin GPIO_PIN_12
#define MINUT2_GPIO_Port GPIOA
#define MINUT2_EXTI_IRQn EXTI4_15_IRQn
#define TEMP_ADC_ENABLE_Pin GPIO_PIN_12
#define TEMP_ADC_ENABLE_GPIO_Port GPIOC
#define BAT_ADC_ENABLE_Pin GPIO_PIN_9
#define BAT_ADC_ENABLE_GPIO_Port GPIOB

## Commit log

2026-09-19 kicad project
    [LCD_CLOCK.kicad_pcb, LCD_CLOCK.kicad_sch, LCD_CLOCK_BOM.ods]
2026-09-19 3D part
    [LCD_Clock.3mf, LCD_Clock_back.stl, LCD_Clock_boutton.stl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]
2026-09-19 driver program

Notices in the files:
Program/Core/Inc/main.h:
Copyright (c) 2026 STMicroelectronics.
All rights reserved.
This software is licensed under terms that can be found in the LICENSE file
